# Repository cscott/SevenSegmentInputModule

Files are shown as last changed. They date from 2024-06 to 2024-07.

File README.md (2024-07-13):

# Seven Segment Display Input Module
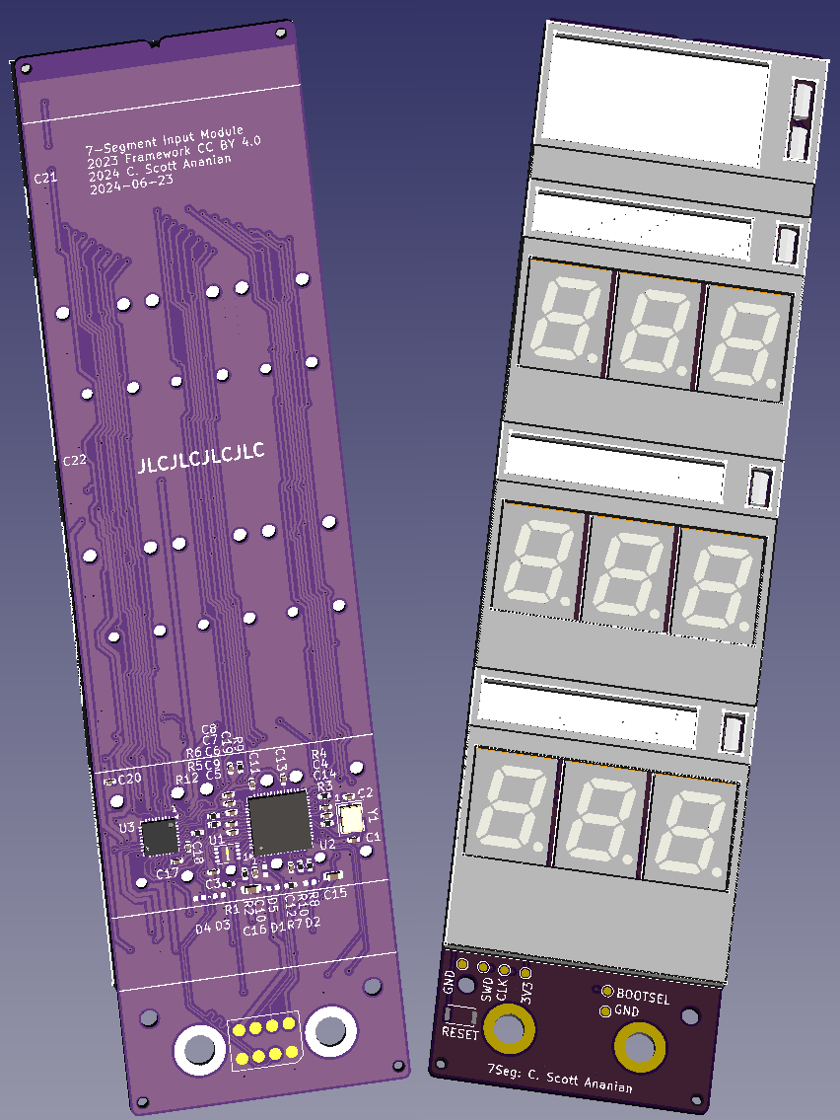
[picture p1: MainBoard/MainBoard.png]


This module is based on the "34x9 LED Matrix" example
from https://github.com/FrameworkComputer/InputModules
and is powered by a Raspberry Pi RP2040 microcontroller.

A short video demo of first light from the prototype is at
https://youtu.be/MXg15aWYOqI

More discussion of this project can be found in the [Framework
forums](https://community.frame.work/t/showcase-7-segment-display-input-module/53807).

## License
Input Modules © 2023 by Framework Computer Inc is licensed under CC BY 4.0.

This seven segment display input module is © 2024 by
C. Scott Ananian and is also licensed under CC BY 4.0.

To view a copy of this license,
visit http://creativecommons.org/licenses/by/4.0/

## Fabrication and Assembly
A 0.8mm PCB is required.

Most components are SMT on the bottom side of the board; the
[seven segment displays](https://www.digikey.com/en/products/detail/vishay-semiconductor-opto-division/VDMR10A1/4327669)
and [side-firing neopixel LEDs](https://www.digikey.com/en/products/detail/adafruit-industries-llc/4691/13170955)
are on the top side.  If you use a PCBA service, it is most economical
to have the bottom side assembled and then hand-solder the small
number of top-side components.

In addition, the [threaded inserts](https://www.digikey.com/en/products/detail/keystone-electronics/24929/16343672) are not generally stocked by JLCPCB
and so are probably easier to hand assemble.

A bezel for the board, which can be 3d printed, can be found in
[LEDMatrix-cover-Body.step](./LEDMatrix-cover-Body.step).  This was
designed in FreeCad and the source is `LEDMatrix-cover.FCStd`.

It is intended that 4mil transparency be used to create legends
for the different sections of the display, and then the entire
top surface be covered with 0.2mm ND film to achieve a consistent
look.  A template for the legends is in
[LEDMatrix-template.pdf](./LEDMatrix-template.pdf) and sample
legends ready to print (or modify!) are in
[LEDMatrix-sample-legends.svg](./LEDMatrix-sample-legends.svg).

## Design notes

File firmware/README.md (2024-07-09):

Basic firmware example for initial bring-up and testing, written
in Circuit Python.

First, install [Circuit Python 8.x for the Adafruit KB2040 board](https://circuitpython.org/downloads),
which is close enough hardware-wise to our board to work.

Then copy `code.py` to the `CIRCUITPY` drive.  This is basic
code to exercise the LED driver.

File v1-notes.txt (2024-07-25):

v1 notes:
* need to order 100nF capacitors for front side
* should have ordered front side stencil from JLCPCB!
x should have used "real" switch footprint for boot/reset so that I could
  mount a switch for initial debugging.
* adjust LED brightness to stay within current limits?

x Should add a power transistor to turn off NEOPIXELs during sleep
  (see qtpy schematic?)
  x place capacitors for U14
x Add a DIP switch (n/p) to Gpio25 for compat w/ LED Matrix
NO ROOM Add pull-down to INTB (GPIO28), again for compat
x Remove unnecessary RESET switch footprint

* Validate max power consumption on actual hardware (once we have
  neopixels) and adjust current limiting resistor values if needed
  to honor our max 100mA limit.  (Ideally a hardware limit, so bad
  software can't force us over our limit into shutdown.  But if the
  max neopixel draw is too high we might need/use a software limit
  for neopixel brightness.)
* Check out visual appearance of hotspots etc from neopixels in
  actual practice, and adjust bezel thicknesses for better printability.
  * maybe squeeze LED digits closer together to free up side space
  * maybe we don't actually need the holes underneath the LED displays
  * maybe nudge neopixels in further from the edge

* Switch to 0.4mm PCB to fix thickness issue
  (an alternative is a two board stackup to drop the board further into the
  well, which could recover another 0.4mm of space but still requires the
  bottom board to be 0.4mm thick.  The bezel would be an additional ~0.8mm
  tall, though and could include the top edge alignment feature)
  Stack would be:
    0.5mm clearance below the PCB (maybe need foam, suggested 0.6mm/24mil foam)
    0.4mm PCB
    2.1mm LED display
    0.1mm ND film (1ply is 1.5mil = 0.04mm. 0.1mm is ~4mil)

  Compared to 3.1 (=2.35+0.75) for indicated thickness to input deck surface

* narrow the bottom PCB (at least), it's pushing max width.
* trim down the top/bottom slightly to allow tint film to wrap around?
----
* clear silkscreen lines on bottom PCB to indicate where the spacer PCB aligns
* legend PCB appears to be slightly longer than spacer?
* trim 1mm (?) from bottom of legend PCB to allow touchpad spacer overlap.
--
* switch to 2020 neopixels?
  - or just plain LEDs?

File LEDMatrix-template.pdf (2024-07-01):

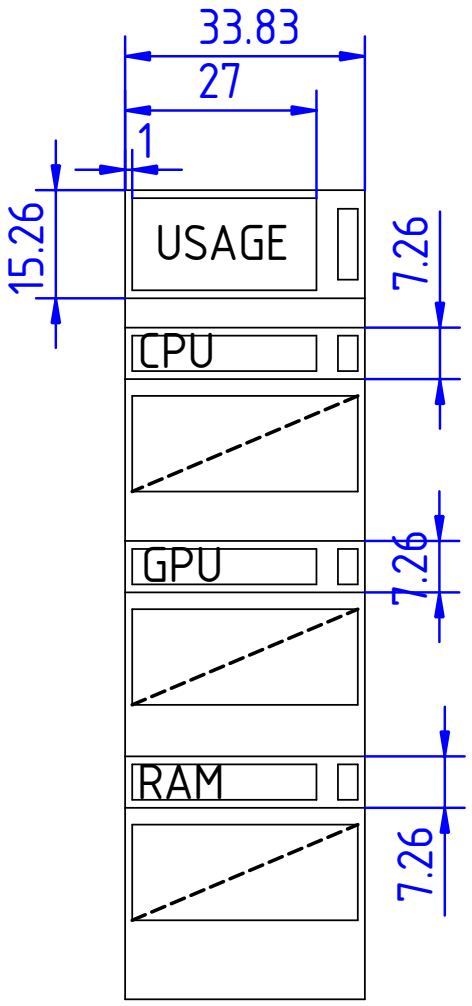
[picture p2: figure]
GPU; USAGE CPU; RAM

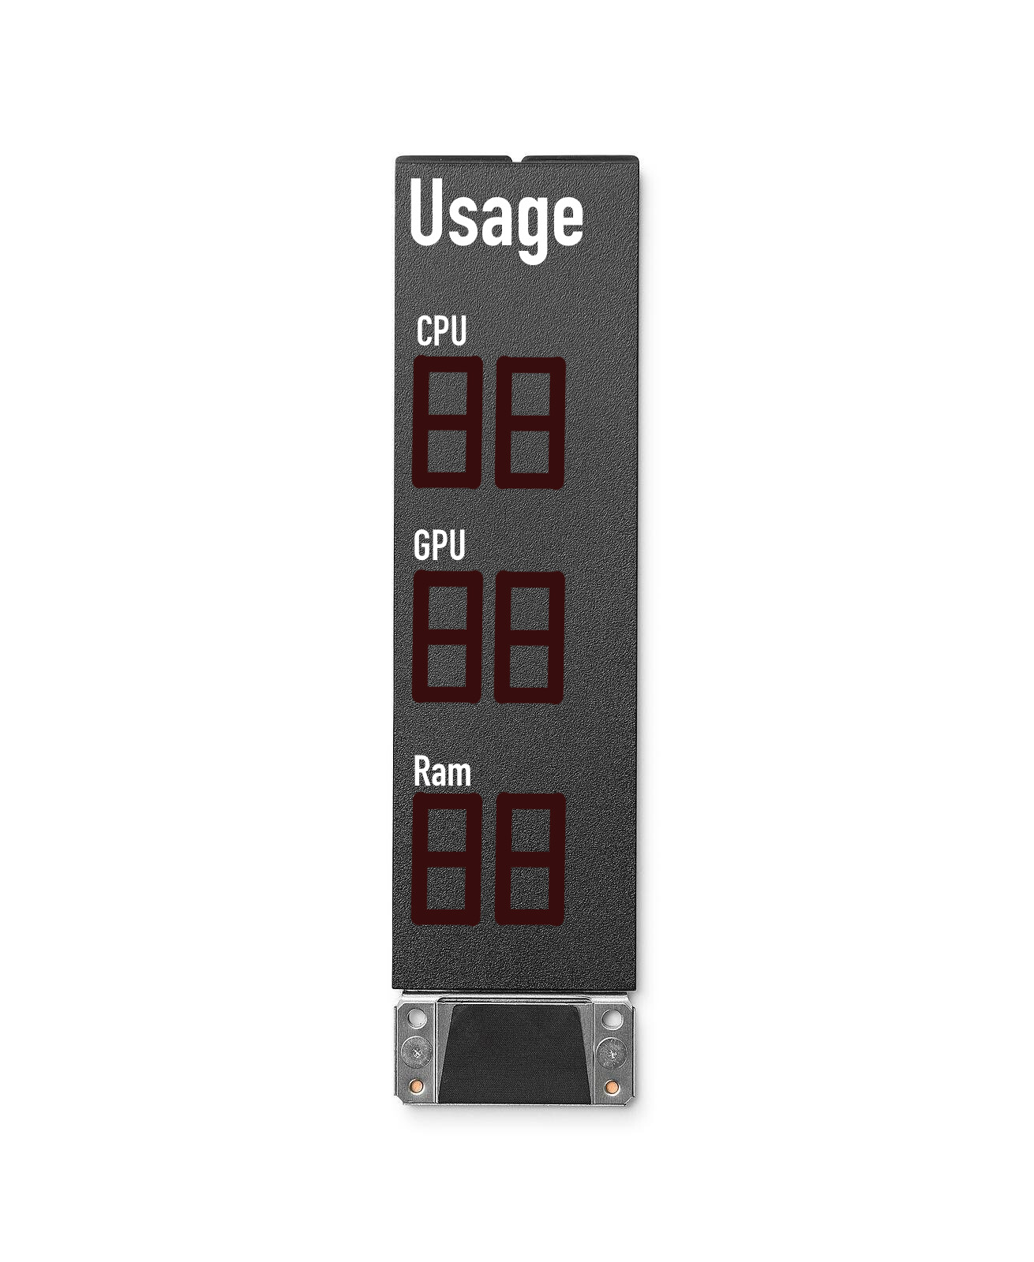
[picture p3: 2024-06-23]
inspiration.jpeg

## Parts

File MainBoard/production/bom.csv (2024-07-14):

Designator | Footprint | Quantity | Value | LCSC Part #
C1, C2 | 0402 | 2 | 22pF | C1555
C10, C11, C12, C13, C14, C18, C19, C20, C21, C22, C24, C25, C26, C27, C3, C4, C5, C7, C9 | 0402 | 19 | 100nF | C1525
C15, C16 | 0603 | 2 | 10uF | C96446
C17, C23, C6, C8 | 0402 | 4 | 1uF | C52923
D1, D2, D3, D4, D5 | 0402 | 5 | D_TVS | C468904
H1, H2 | MountingHole_3.7mm_Pad_24929 | 2 | 24929 | C5354888
LED1, LED2, LED3, LED4, LED5, LED6, LED7, LED8 | LED-SMD_4P-L5.0-W5.0-BL_XL-5050RGBC | 8 | SKC6812RGBW-BW-B
R1, R3 | 0402 | 2 | 1k | C11702
R10, R8 | 0402 | 2 | 2k | C4109
R11, R13 | 0603 | 2 | 5.1 | C25197
R12 | 0402 | 1 | 33k | C25779
R14 | 0603 | 1 | 470k | C23178
R2, R4 | 0402 | 2 | 10k | C25744
R5, R6 | 0402 | 2 | 22 | C25092
R7 | 0603 | 1 | 300k | C23024
R9 | 0402 | 1 | 100k | C25741
U1 | SON-8-1EP_3x2mm_P0.5mm_EP0.2x1.6mm | 1 | W25Q16JVUXIQ | C2843335
U10, U11, U12, U4, U5, U6, U7, U8, U9 | SON_R10A1_VIS_mod_noholes | 9 | VDMR10A1 | C5821326
U13 | SOT-353_L2.1-W1.3-P0.65-LS2.3-BR | 1 | 74LVC1G34GW,125 | C455045
U14 | SOT-363_L2.0-W1.3-P0.65-LS2.1-BR | 1 | SIP32431DR3-T1GE3 | C141606
U2 | QFN-56-1EP_7x7mm_P0.4mm_EP3.2x3.2mm | 1 | RP2040 | C2040
U3 | Texas_RSN_WQFN-32-1EP_4x4mm_P0.4mm_EP2.8x2.8mm_ThermalVias | 1 | IS31FL3729-QFLS4-TR | C2940549
Y1 | Crystal_SMD_3225-4Pin_3.2x2.5mm | 1 | 12.000MHz | C9002

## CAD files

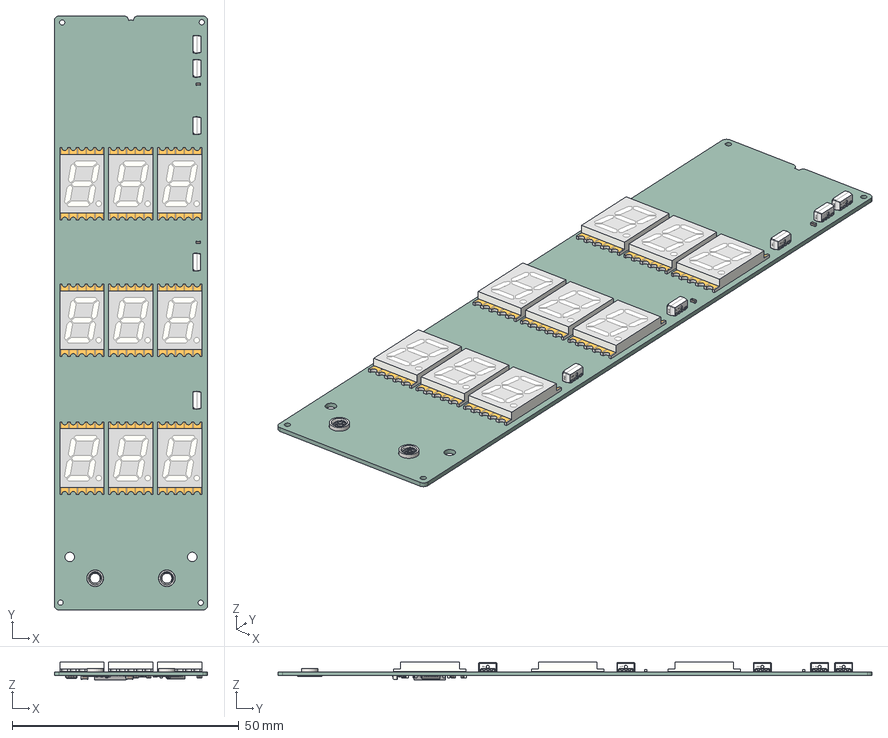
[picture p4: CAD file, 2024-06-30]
MainBoard/MainBoard.step
33.8 x 131.0 x 3.95 mm
vdmx10a1 x 9
C_0402_1005Metric x 20
LED-SMD_WS2812B-4020 x 5
QFN_56_1EP_7x7mm_P04mm_EP32x32mm
R_0402_1005Metric x 11
C_0603_1608Metric x 2
Crystal_SMD_3225-4Pin_3.2x2.5mm
QFN-32_L4.0-W4.0-H0.8-P0.40-BL-EP2.8
_autosave-LEDMatrix_PCB

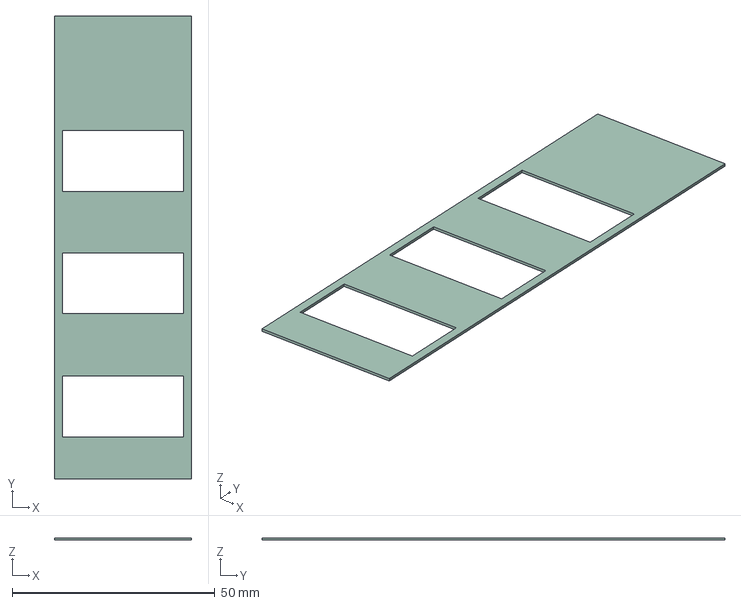
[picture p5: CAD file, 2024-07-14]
Bezel/Bezel.step
33.8 x 114.2 x 0.6 mm

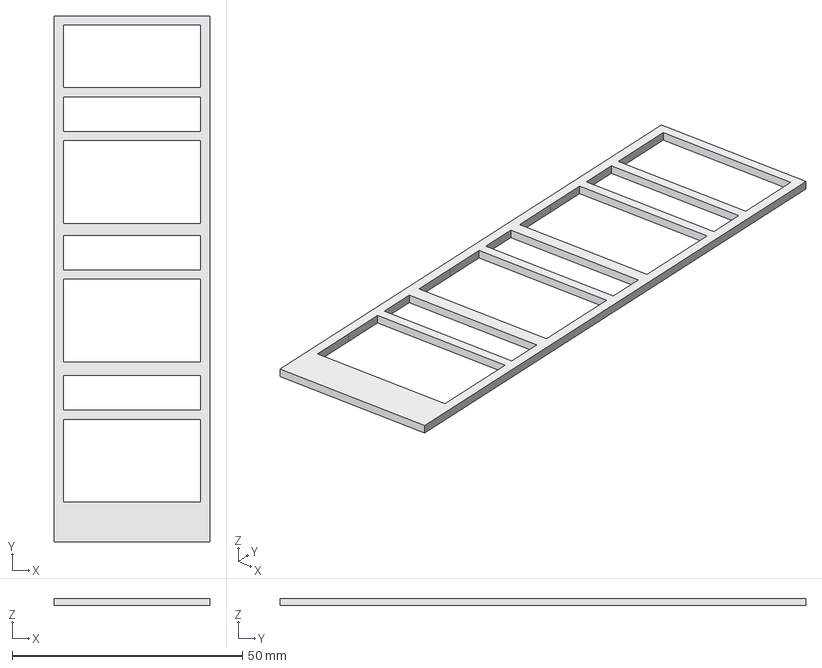
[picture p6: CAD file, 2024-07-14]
LEDMatrix-cover-alt.FCStd
33.8 x 114.2 x 1.60 mm

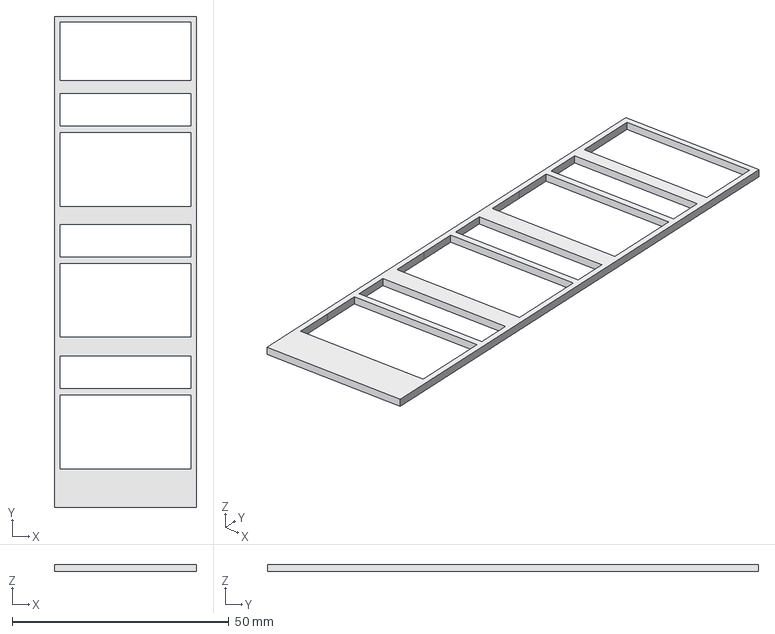
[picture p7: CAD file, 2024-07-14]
LEDMatrix-cover-Body.step
32.8 x 113.2 x 1.60 mm

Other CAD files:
LEDMatrix-cover.FCStd

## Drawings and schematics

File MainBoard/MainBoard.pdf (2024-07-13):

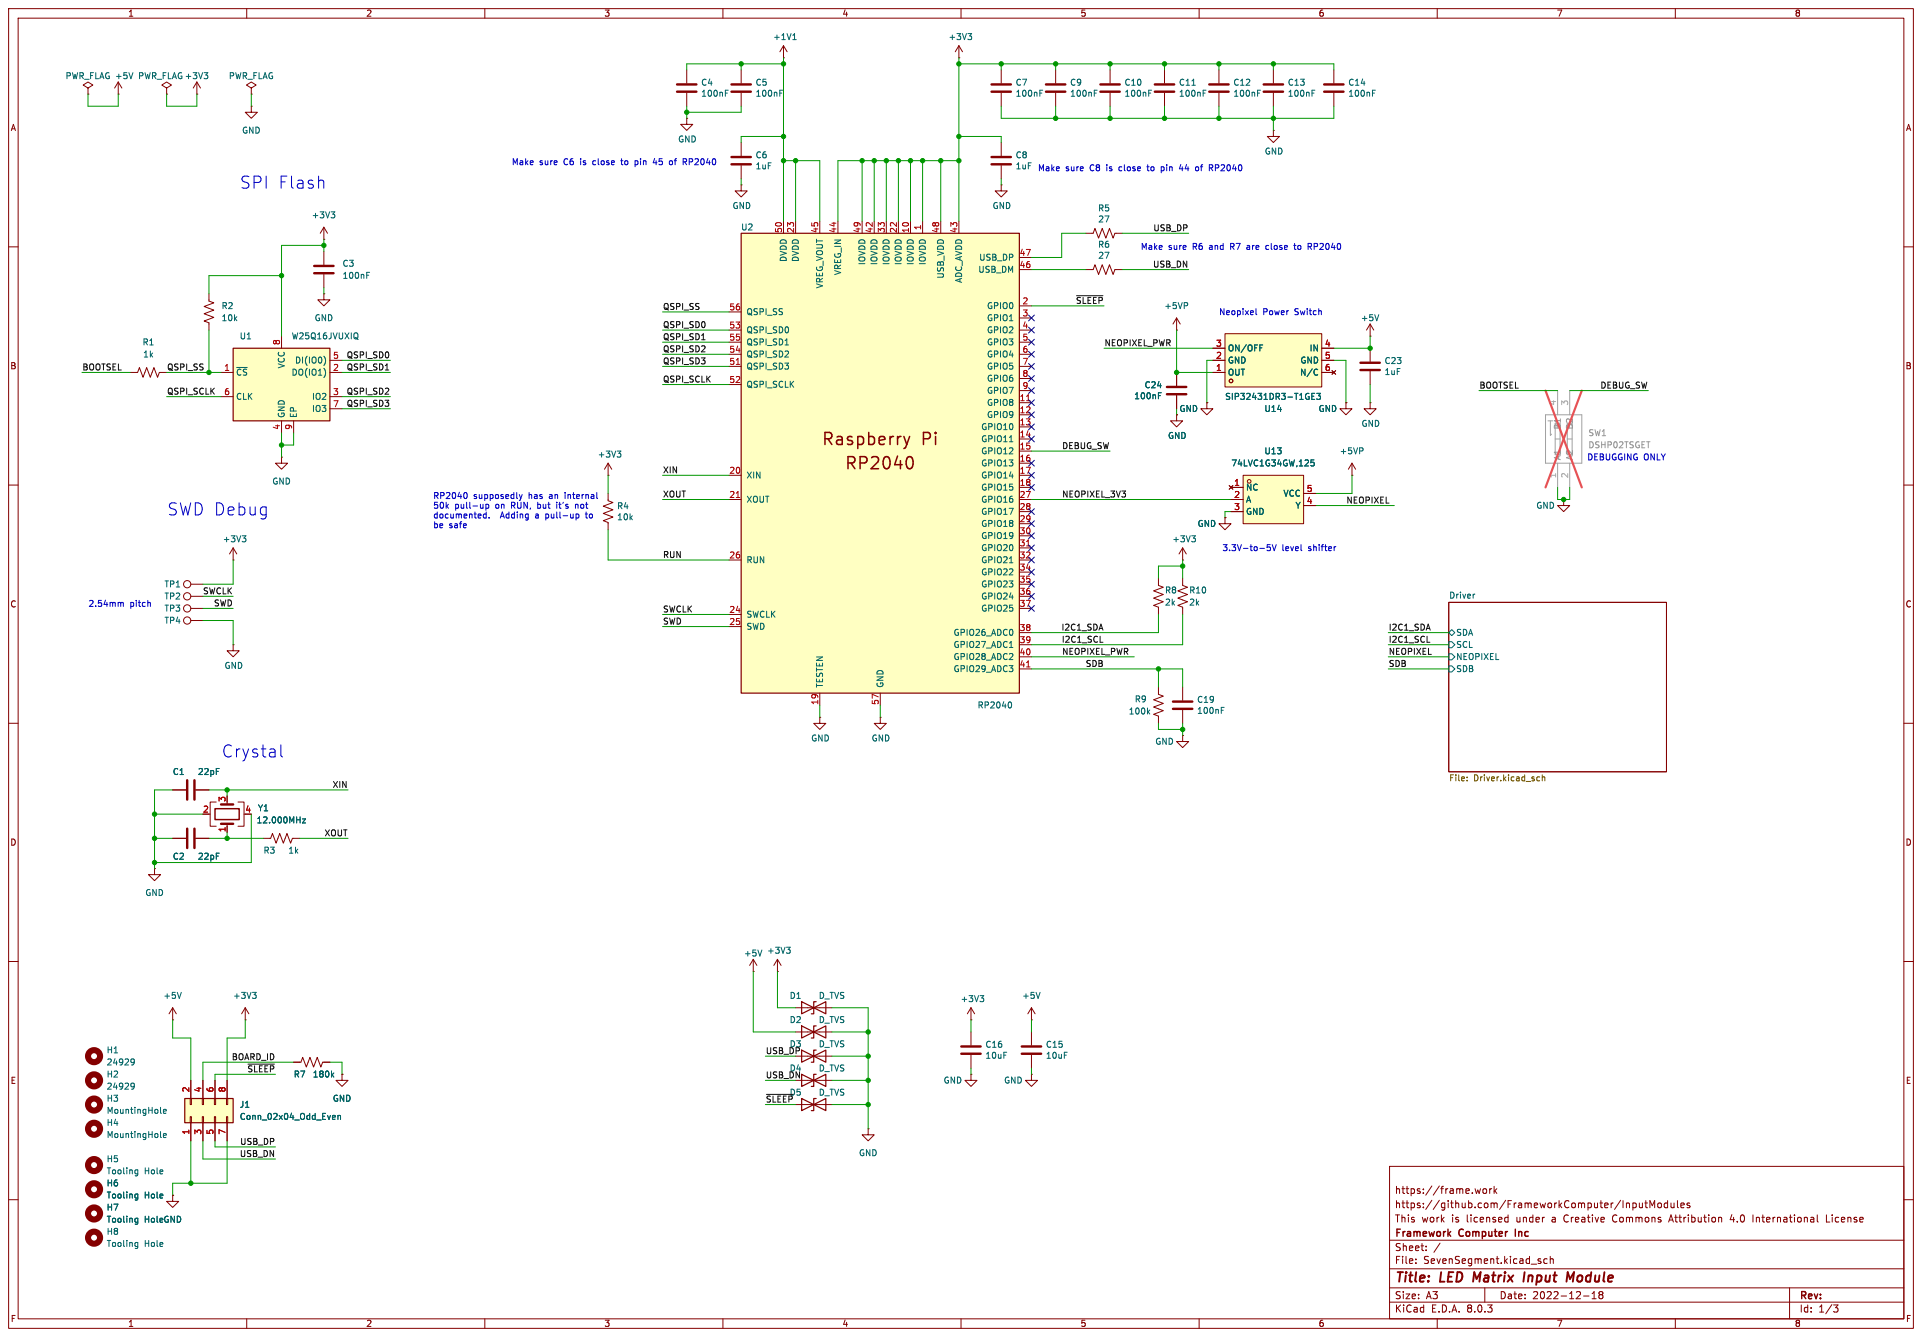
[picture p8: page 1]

1 IOVDD 10 GPIO8 11 GPIO9 12 GPIO10 13 GPIO11 14 GPIO12 15 GPIO13 16 GPIO14 17 GPIO15 18 TESTEN 19 GPIO0 2 XIN 20 XOUT 21 IOVDD 22 DVDD 23 SWCLK 24 SWD 25 RUN 26 GPIO16 27 GPIO17 28 GPIO18 29 GPIO1 3 GPIO19 30 GPIO20 31 GPIO21 32 IOVDD 33 GPIO22 34 GPIO23 35 GPIO24 36 GPIO25 37 GPIO26_ADC0 38 GPIO27_ADC1 39 GPIO2 4 GPIO28_ADC2 40 GPIO29_ADC3 41 IOVDD 42 ADC_AVDD 43 VREG_IN 44 VREG_VOUT 45 USB_DM 46 USB_DP 47 USB_VDD 48 IOVDD 49 GPIO3 5 DVDD 50 QSPI_SD3 51 QSPI_SCLK 52 QSPI_SD0 53 QSPI_SD2 54 QSPI_SD1 55 QSPI_SS 56 GND 57 GPIO4 6 GPIO5 7 GPIO6 8 GPIO7 9 U2 RP2040 GND

SIP32431DR3-T1GE3 OUT 1 GND 2 ON/OFF 3

SCL SDB NEOPIXEL Driver File: Driver.kicad_sch C15

H6 Tooling Hole H7 Tooling Hole

https://frame.work
https://github.com/FrameworkComputer/InputModules

Id: 1/3 Title: LED Matrix Input Module

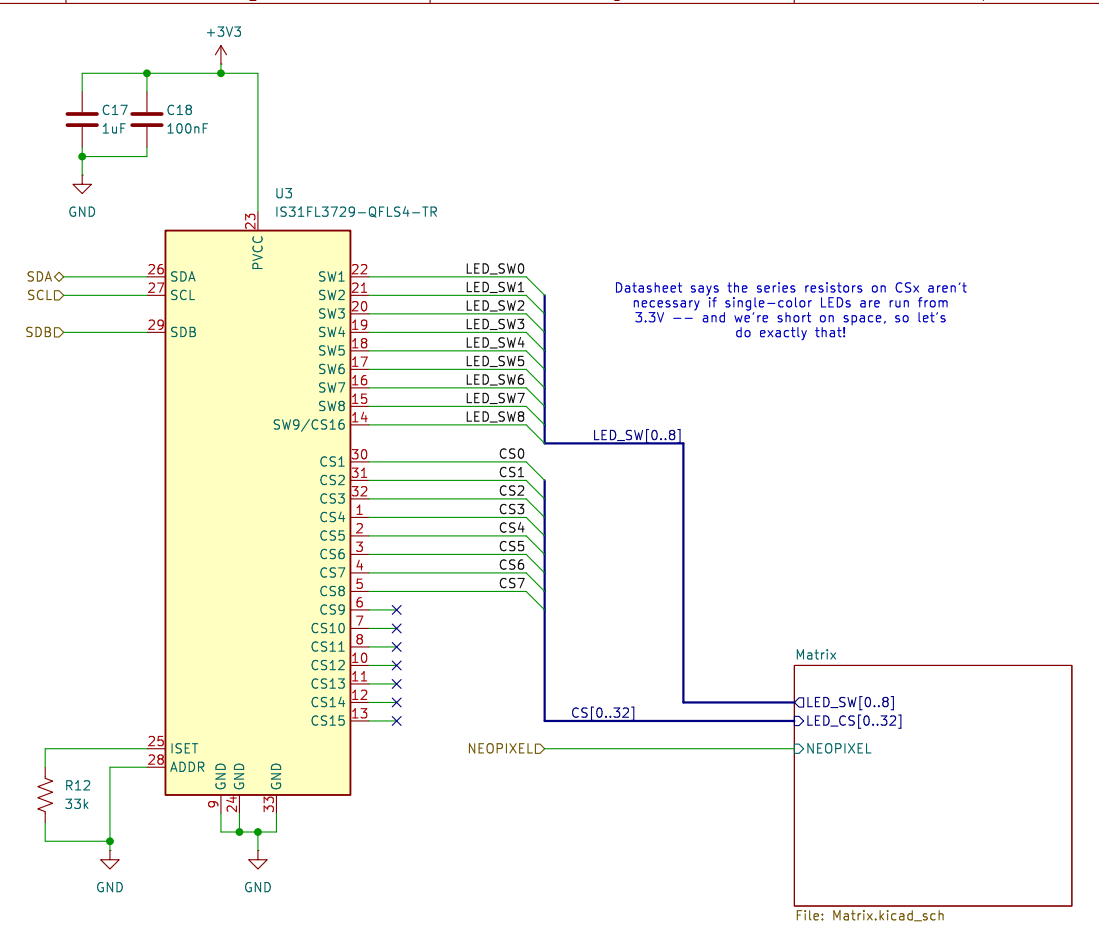
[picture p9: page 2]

https://frame.work
https://github.com/FrameworkComputer/InputModules

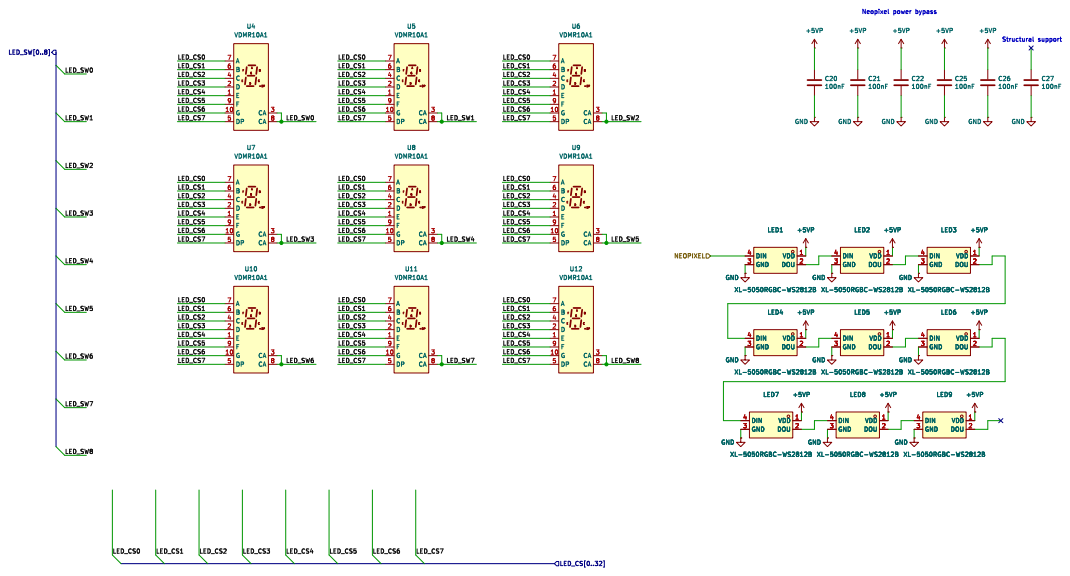
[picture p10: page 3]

100nF VDD 1 DOU 2 GND 3 DIN 4

VDD 1 DOU 2 GND 3 DIN 4

https://frame.work
https://github.com/FrameworkComputer/InputModules

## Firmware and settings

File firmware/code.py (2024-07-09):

# SPDX-FileCopyrightText: 2021 Kattni Rembor for Adafruit Industries
# SPDX-License-Identifier: MIT
"""CircuitPython I2C Device Address Scan"""
import time
import board
import busio
import microcontroller
from digitalio import DigitalInOut

#i2c = board.I2C()  # uses board.SCL and board.SDA
# i2c = board.STEMMA_I2C()  # For using the built-in STEMMA QT connector on a microcontroller

# To create I2C bus on specific pins
# import busio
i2c = busio.I2C(microcontroller.pin.GPIO27, microcontroller.pin.GPIO26)

while not i2c.try_lock():
    pass

LED_ADDR = 0x34

def reg_write(reg, value):
    i2c.writeto(LED_ADDR, bytes([reg, value]))
def reg_read(reg):
    result = bytearray(1)
    i2c.writeto_then_readfrom(LED_ADDR, bytes([reg]), result)
    return result[0]

try:
    # bring out of hardware shutdown
    SDB = DigitalInOut(microcontroller.pin.GPIO29)
    SDB.switch_to_output(True)
    # reset the chip
    reg_write(0xCF, 0xAE)
    # configure the chip: 9SWx15CS, LGC=0 (?), enable short detect
    reg_write(0xA0, 0x01)
    print("Config:", hex(reg_read(0xA0)))
    # short detect
    reg_write(0xA1, 0x01)
    reg_write(0xA0, 0x03) # open detect
    for reg in range(0xB3, 0xC5):
        print("Open?", hex(reg), hex(reg_read(reg)))
    reg_write(0xA0, 0x05) # short detect
    for reg in range(0xB3, 0xC5):
        print("Short?", hex(reg), hex(reg_read(reg)))
    reg_write(0xA0, 0x01)
    # max brightness! (GCC)
    reg_write(0xA1, 0x40)
    print(hex(reg_read(0xA1)))
    for reg in range(0x90, 0xA0):
        reg_write(reg, 0xFF)
    # first segment on
    reg_write(0x01, 0xFF)
    for reg in range(0x02, 0x90):
        time.sleep(0.05)
        print(reg)
        reg_write(reg, 0xFF)
        #reg_write(reg-1, 0x00)

finally:  # unlock the i2c bus when ctrl-c'ing out of the loop
    i2c.unlock()

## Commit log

2024-06-23 Initialize repo with copy of Framework Microcontroller Input Module sample
    [MicrocontrollerInputModule.kicad_pcb, MicrocontrollerInputModule.kicad_sch]
2024-06-23 Switch to basing this on the LED Matrix example module
    [Driver.kicad_sch, LEDMatrix.kicad_pcb, LEDMatrix.kicad_sch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]
2024-06-23 Schematic done, partially routed
    [Driver.kicad_sch, LEDMatrix.kicad_pcb, LEDMatrix.kicad_sch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]
2024-06-24 Routing complete but not DRC clean
    Also want to add 3-9 neopixels here to backlight the legend.
    [Driver.kicad_sch, LEDMatrix.kicad_pcb, LEDMatrix.kicad_sch]
2024-06-25 Finished version w/ legend on silkscreen, DRC clean
    [Driver.kicad_sch, LEDMatrix.kicad_pcb, LEDMatrix.kicad_sch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]
2024-06-25 Version 2, with right angle neopixel backlighting
    [Driver.kicad_sch, LEDMatrix.kicad_pcb, LEDMatrix.kicad_sch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]
2024-06-25 Tweaks from JLCDFM tools, mostly moving vias away from pads
    [LEDMatrix.kicad_pcb, bom.csv, positions.csv]
2024-06-29 Another update before sending to JLCPCB
    1. Narrowed the spacing between the LED displays
    2. Made the position of the neopixels more consistent
    3. Extended the silkscreen up a bit
    4. Added my name to the front of the board
    5. Designed the enclosure grid
    [Driver.kicad_sch, LEDMatrix-cover-Body.step, LEDMatrix-cover.FCStd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]
2024-06-29 Tweaks to the 3d models
    [LEDMatrix-cover.FCStd, LEDMatrix.kicad_pcb, LEDMatrix.step]
2024-06-30 Update 3d models
    [LEDMatrix.kicad_pcb, LEDMatrix.kicad_sch, LEDMatrix.step]
2024-06-30 Adjust board thickness to 0.8mm
    [LEDMatrix.kicad_pcb, LEDMatrix.step]
2024-07-01 Improve docs, add legend template and sample
2024-07-02 Tweak led matrix cover for manufacturability
    Thinnest wall is now 0.8mm.
    [LEDMatrix-cover-Body.step]
2024-07-11 Rename KiCad project from "LEDMatrix" to "SevenSegment"
    [Driver.kicad_sch, SevenSegment.kicad_pcb, SevenSegment.kicad_sch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]
2024-07-11 Update design
    New features:
    * Power switch for NEOPIXEL to save power when sleeping
    * Level translator from 3.3V to 5V for neopixel for hygiene
    * Use "real" DIP switch footprint for debug/boot buttons, even
    if this is going to be unpopulated in practice, since both
    these modes can be entered via software. Still can be populated
    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
    [Matrix.kicad_sch, SevenSegment.kicad_pcb, SevenSegment.kicad_sch]
2024-07-12 Add 7-seg display datasheet; fix FreeCad error in bezel; add notes
    [LEDMatrix-cover.FCStd]
2024-07-13 CAD updates
    [LEDMatrix-cover.FCStd]
2024-07-13 Push 7-segment displays to 0.1mm spacing to allow 2mm min bezel width
    We want to try using a PCB as the legend shadow mask, and JLCPCB requires
    a minimum PCB width of 2mm to avoid breakage during routing. That would
    also make our 3d-printed spacer more printable as well, win-win. Hopefully
    this will still pass JLCPCB's assembly clearances, otherwise I'm stenciling
    these all myself.
    [Matrix.kicad_sch, SevenSegment.kicad_pcb]
2024-07-13 Switch from sidelight LEDs for labels to backlight LEDs
    I'm not certain there's enough distance for proper diffusion, but
    let's try it. The sidelight LEDs leaked light everywhere and we're
    bright enough on the left-hand side.
    [Matrix.kicad_sch, SevenSegment.kicad_pcb, bom.csv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]
2024-07-13 Move main PCB into subdirectory so that we can add a bezel PCB to this repo
    [Driver.kicad_sch, MainBoard.kicad_pcb, MainBoard.kicad_sch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]
2024-07-14 Add Bezel PCB; adjust legend locations
    [Bezel.kicad_pcb, Bezel.kicad_sch, MainBoard.kicad_pcb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]
2024-07-14 Remove LED modules from Bezel PCB; generate production files
    [Bezel.kicad_pcb]
2024-07-14 Optimize for manufacturability (use JLCPCB basic parts, etc)
    [MainBoard.kicad_pcb, MainBoard.kicad_sch, bom.csv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]
2024-07-14 Update the 3d printed spacer for the new design
    [Bezel.kicad_pcb, Bezel.step, LEDMatrix-cover-Body.step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]
2024-07-14 Add neopixel debugging header
    This allows us to fab just the neopixels on the board, saving some cost
    while we check to see how the backlight looks.
    [MainBoard.kicad_pcb, MainBoard.kicad_sch, designators.csv]
2024-07-14 Switch Neopixel component type to match something JLCPCB is happy to assemble
    [MainBoard.kicad_pcb, Matrix.kicad_sch, bom.csv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]
2024-07-14 Fabricate the spacer as a PCB, too
    Since the spacer needed to be exactly 1.6mm thick, and JLCPCB wouldn't
    3d-print something thinner than 2mm thick, lets make the spacer a PCB
    as well!
    [LEDMatrix-cover-alt.FCStd, Spacer.kicad_pcb, Spacer.kicad_sch]
2024-07-25 more notes from testing the v2 boards
2024-07-25 Add spacer cutout to user layer on MainBoard PCB; add various alt LED parts
    Not quite sure whether to go with smaller neopixels or just plain white
    LEDs. Added LCSC parts for both to the LCSC library.
    [MainBoard.kicad_pcb]
